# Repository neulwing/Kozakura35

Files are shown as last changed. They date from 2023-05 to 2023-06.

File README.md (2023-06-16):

# Kozakura KZ-35 QAZ-Inspired 35% Keyboard
Special thanks to u/daninjah - Cheers for the 3D printing and prototyping. (TдT)

## Project on hold, I have decided to learn Fusion 360, and make a better looking case. ##

## Introduction
_Kozakura,「小桜」,「こざくら」means "Little Cherry Blossom"._

The KZ-35 is a bottom mount keyboard based on the QAZ 35% layout. The project is intended to be freely 3D-printable and a fun little project for those hand-wiring their first keyboard.

The case is seamless and in one solid piece. No need for a top cover as the screws are hidden underneath the keycaps.

Underneath there is a large window to show off your hand-wiring work along with the Kozakura symbol. There are also indents for 8mm rubber dome bumpers.

Inside the case there is a stand for a Pro-Micro. The USB hole supports USB-C and micro-USB.

## Layout Comparison between KZ-35 and QAZ
Both layouts are 10.25u in width by 4u in depth.
KZ Colourised
QAZ_Colourised

## Materials
### IMPORTANT
### The case and plate are designed to be printed with PLA. ###
### The plate needs a stiff material otherwise it would be flexible enough to be bombastic like Mr. Fantastic. ###

### Tools
- Soldering Iron
- Screwdriver (Phillips head)

### Electronics
- Pro-Micro (18mmx33mm or smaller) or alternative microcontroller. (I recommend Waveshare RP2040 Zero for KMK)
- 35 Cherry MX Style Mechanical switches
- 35 1N4148 Diodes
- Wires or Brass bars/tubing
- Rainbow Ribbon Cable
- Insulation (Heatshrink, Polyamide/Electrical Tape)

### Hardware 
- 4* M2 Screws 8mm long.
- 4* Heat-set insert M2 Knurled nuts
- Clear Tamiya Pla Plate
- Glue
- Double-sided tape or Hot-glue.
- 8mm Rubber dome bumpers (for feet)

### Keycaps
- 31* 1u
- 3* 1.25u
- 1* 6.25u

### Optional
- 4* 4mmx1mmx1.5mm O-rings (Recommended)
- Blunt tip for Soldering Iron
- Sandpaper
- Paint

## TODO
- Draw a Waifu for the keebweebz.
- Make a build video showing the full process and sound-test. Upload to Youtube.
- Write a "Lessons learned" article documenting the information that I struggled to find in my research. This could pave the way for newcomers in the keyboard design space.
- Finish writing README.md
- Create aesthetically pleasing graphics to illustrate this page.

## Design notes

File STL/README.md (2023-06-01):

**[DISCLAIMER]
All files are provided without warranty or any guarantee that they will work. Please proceed at your own risk.**

### IMPORTANT
### The case and plate are designed to be printed with PLA. ###
### The plate needs a stiff material otherwise it would be flexible enough to be bombastic like Mr. Fantastic. ###

https://github.com/neulwing/Kozakura35/assets/44045041/f559dc3d-74d7-41dd-807f-670080df0991

Video Credit: u/daninjah

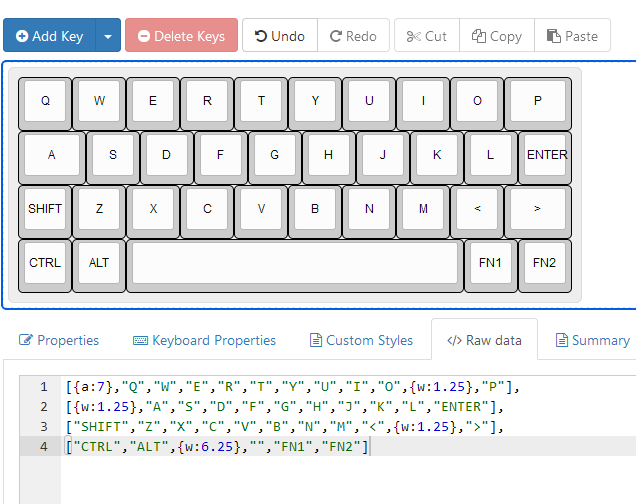
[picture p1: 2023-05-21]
Images/KLE.png

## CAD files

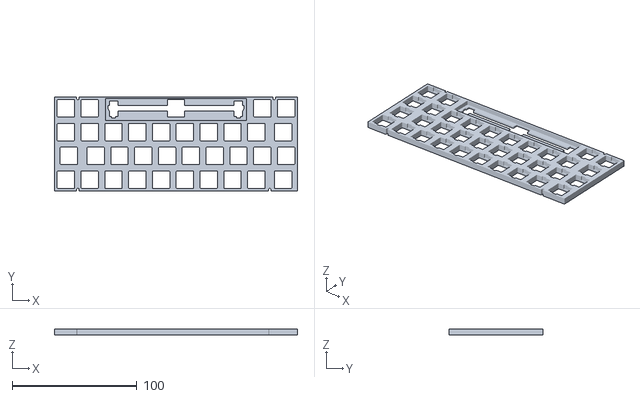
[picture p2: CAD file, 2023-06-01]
STL/KZ-35 Plate.stl
194.5 x 75.4 x 5.00

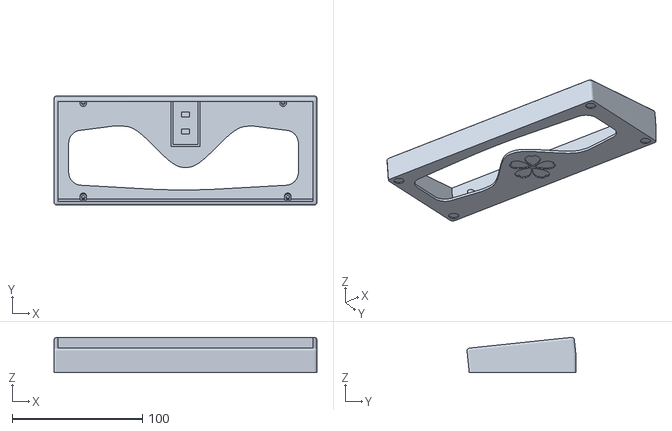
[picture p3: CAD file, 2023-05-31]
STL/KZ-35 Case.stl
202.1 x 83.8 x 27.1

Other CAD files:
Blender Models/Case.blend
Blender Models/Plate.blend

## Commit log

2023-05-24 Add files via upload
    v1.2
    - Switch holes increased from 13.9mm to 14mm
    - Screw cutouts reduced from 2.1mm to 2.0mm
    - Stabilizer indented area increased from 1.5mm to 1.6mm thick.
    [Plate.blend]
2023-05-25 Add files via upload
    Version 1.2
    - Side walls raised by 2.8mm to fully cover the switches. Cherry MX specs say 6.6mm is above plat. An extra 0.2mm is included to accommodate the O-ring mod.
    - New Pro-micro stand design based on Pro-micro Arduino Leonardo Pro Micro Box by abelbluelight. - https://www.thingiverse.com/thing:320421
    - New Pro-micro stand, can now accomodate thick double-sided tape.
    - USB-C hole made smaller.
    - Blend file reorganised and cleaned up.
    - Added back the Sakura flower design that was missing.
    [Case.blend]
2023-05-25 Add files via upload
    - Side walls raised by 2.8mm to fully cover the switches. Cherry MX specs say 6.6mm is above plat. An extra 0.2mm is included to accommodate the o-ring mod.
    - New Pro-micro stand design, can now accomodate double-sided tape.
    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
    [KZ-35 Case.stl]
2023-05-30 Add files via upload
    Version 1.4
    - Height reduced to 26.1mm from 27.5mm.
    - Increased tolerance between plate and case inner walls by 0.4 per side.
    [Case.blend]
2023-05-30 Add files via upload
    - Added a lip to the bottom of the plate to stop the spacebar switch from buckling.
    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
    [Plate.blend]
2023-05-30 Add files via upload
    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
    [KZ-35 Case.stl]
2023-05-30 Add files via upload
    - Added a lip to the bottom to stop the plate from buckling underneath the spacebar.
    [KZ-35 Plate.stl]
2023-05-31 Add files via upload
    - Re-exported the STL as it was causing issues in the slicer.
    [KZ-35 Case.stl]
2023-05-31 Add files via upload
    - Re-exported the STL file. Now it slices correctly in Cura.
    [KZ-35 Case.stl]
2023-05-31 Add files via upload
    - Fixed Window mesh, so that it can now export into STL with no issues.
    [Case.blend]
2023-06-01 Add files via upload
    - Reduced plate width by 0.8mm
    - Reduced plate depth by 0.8mm
    [KZ-35 Plate.stl]
